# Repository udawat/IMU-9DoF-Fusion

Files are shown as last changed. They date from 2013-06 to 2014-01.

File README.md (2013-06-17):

IMU-9DoF-Fusion
===============

Explore Labs' 9 Degrees of Freedom Inertial Measurement Unit with MPU-6150 and HMC5883L and Auto Voltage Level Shifting

To work with the Code, you need the libraries installed at the right place.
Following libraries are required to be copied inside the libraries folder:

I2Cdev - by Jeff Rowberg

MPU6050 - The library for MPU-6050 and MPU-6150 are Code Compatible - by Jeff Rowberg

HMC5883L - by Jeff Rowberg

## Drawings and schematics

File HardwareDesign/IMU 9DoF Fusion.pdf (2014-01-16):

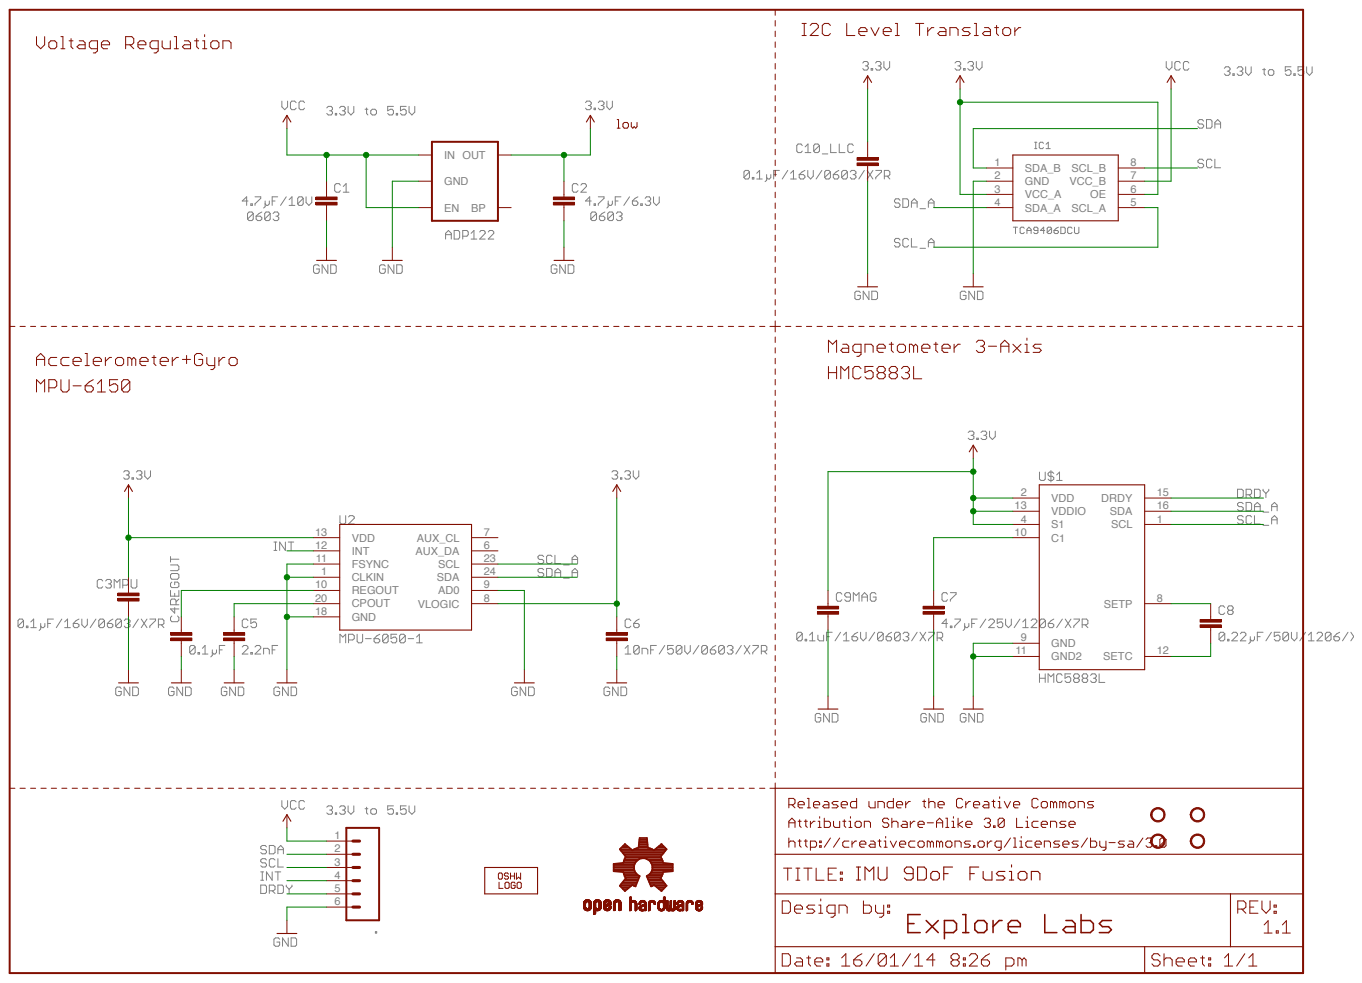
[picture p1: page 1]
VDD 13 INT 12 FSYNC 11; CLKIN; 1 REGOUT 10 CPOUT 20 GND 18; AUX_CL; AUX_DA; SCL; SDA; VLOGIC; VDD; 2 VDDIO 13; 1 SDA; SETP; SETC; DRDY; GND; 9 GND2 11; OUT; SDA_B; VCC_A; SDA_A; SCL_A; 6 VCC_B; 7 SCL_B

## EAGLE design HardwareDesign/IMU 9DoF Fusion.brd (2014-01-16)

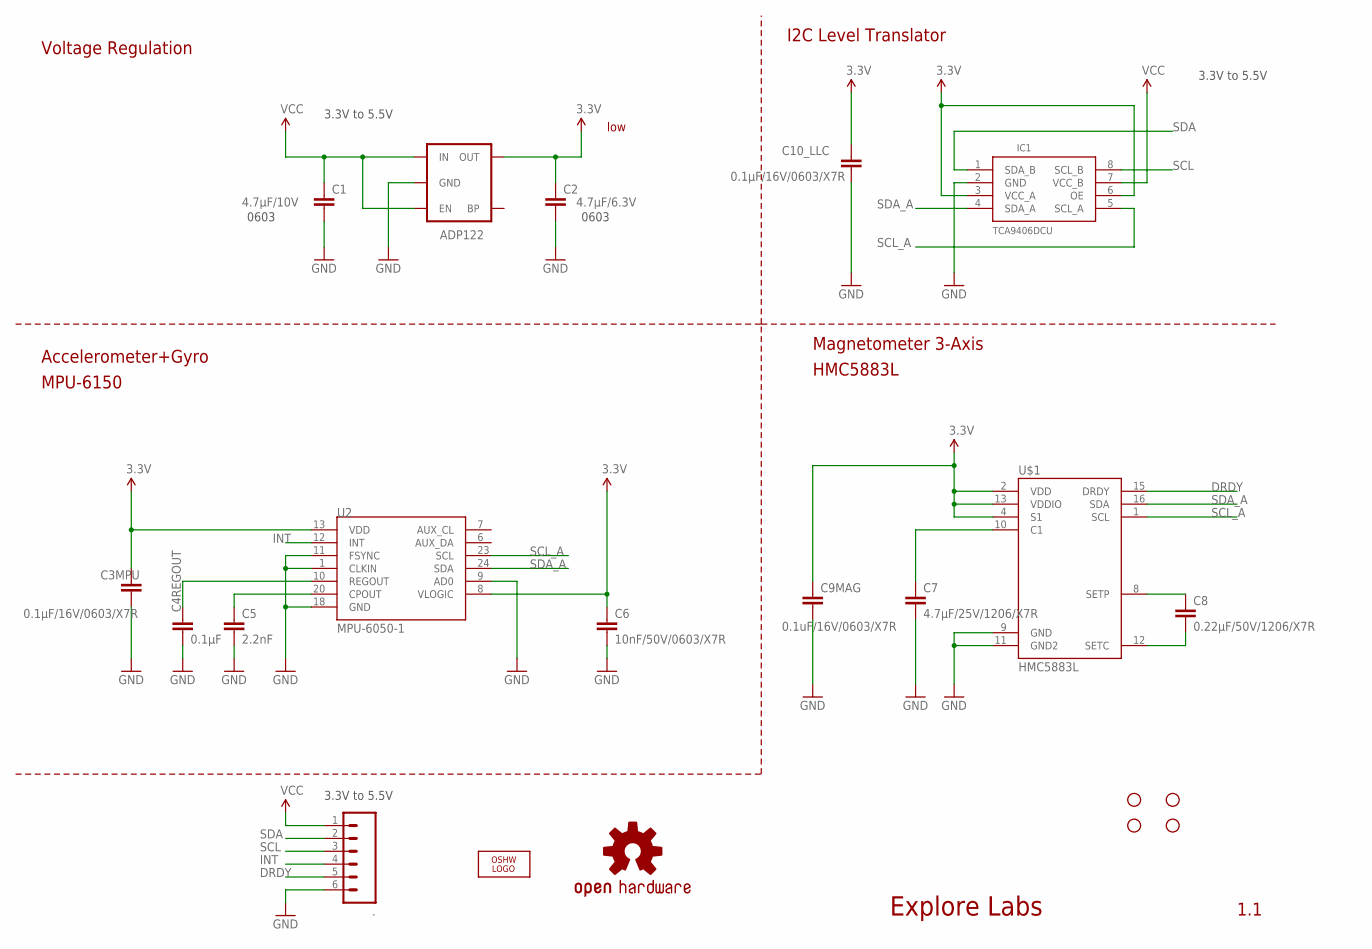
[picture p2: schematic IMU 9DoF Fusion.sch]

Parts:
.: M06SIP; 1X06
ADP122: V_REG_LDOSMD; SOT23-5
C1: 4.7µF/10V; 0603-CAP
C2: 4.7µF/6.3V; 0603-CAP
C3MPU, C10_LLC: 0.1µF/16V/0603/X7R; 0603-CAP
C4REGOUT: 0.1µF; 0603-CAP
C5: 2.2nF; 0603-CAP
C6: 10nF/50V/0603/X7R; 0603-CAP
C7: 4.7µF/25V/1206/X7R; 1206
C8: 0.22µF/50V/1206/X7R; 1206
C9MAG: 0.1uF/16V/0603/X7R; 0603-CAP
IC1: TCA9406DCU; VSSOP8
JP1, JP3, JP4, JP5: STAND-OFFTIGHT; STAND-OFF-TIGHT
LOGO1: OSHW_LOGO_FILLX0150-NT; OSHW_FILLX150_NOTEXT
U2: MPU-6050-1; QFN-24-4MM2
U$1: HMC5883L; LPCC16
U$2: OSHW-LOGOS; OSHW-LOGO-S

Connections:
3.3V: ADP122.5 (OUT), C2.1, C3MPU.1, C6.1, C9MAG.1, C10_LLC.1, IC1.3 (VCC_A), IC1.6 (OE), U2.8 (VLOGIC), U2.13 (VDD), U$1.2 (VDD), U$1.4 (S1), U$1.13 (VDDIO)
CPOUT: C5.1, U2.20 (CPOUT)
DRDY: ..5, U$1.15 (DRDY)
GND: ..6, ADP122.2 (GND), C1.2, C2.2, C3MPU.2, C4REGOUT.2, C5.2, C6.2, C7.2, C9MAG.2, C10_LLC.2, IC1.2 (GND), U2.1 (CLKIN), U2.9 (AD0), U2.11 (FSYNC), U2.18 (GND), U$1.9 (GND), U$1.11 (GND2)
INT: ..4, U2.12 (INT)
unnamed: C7.1, U$1.10 (C1)
unnamed: C8.1, U$1.8 (SETP)
unnamed: C8.2, U$1.12 (SETC)
REGOUT: C4REGOUT.1, U2.10 (REGOUT)
SCL: ..3, IC1.8 (SCL_B)
SCL_A: IC1.5 (SCL_A), U2.23 (SCL), U$1.1 (SCL)
SDA: ..2, IC1.1 (SDA_B)
SDA_A: IC1.4 (SDA_A), U2.24 (SDA), U$1.16 (SDA)
VCC: ..1, ADP122.1 (IN), ADP122.3 (EN), C1.1, IC1.7 (VCC_B)

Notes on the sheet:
Explore Labs
1.1
3.3V to 5.5V
I2C Level Translator
Voltage Regulation
MPU-6150
HMC5883L
Magnetometer 3-Axis
Accelerometer+Gyro
0603
low

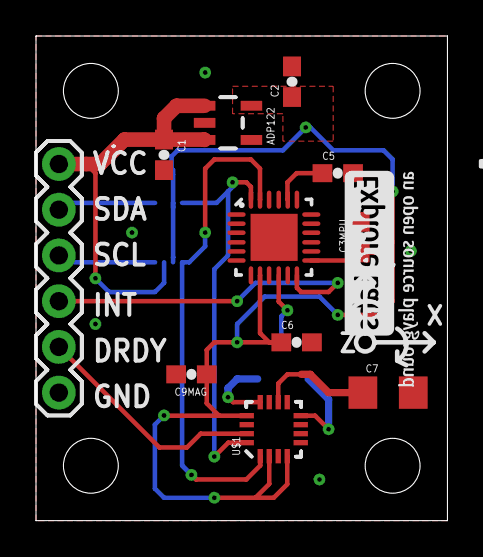
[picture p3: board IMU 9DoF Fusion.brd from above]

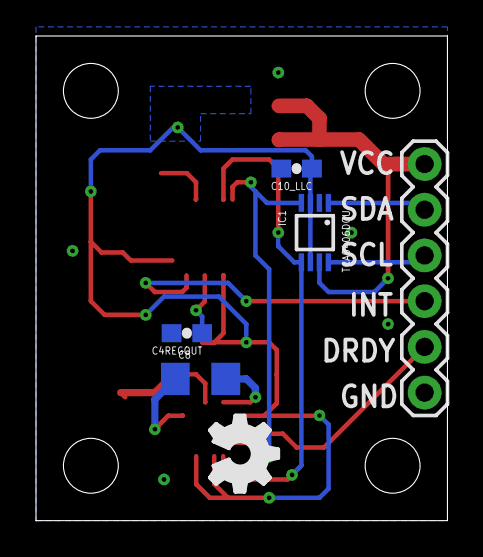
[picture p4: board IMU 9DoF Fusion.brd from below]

Board: 2 copper layers, 22.9 x 26.9 mm, 22 parts (6 on the bottom side), 14 nets.

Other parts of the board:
U$3: EXLABS_LOGO_0.25

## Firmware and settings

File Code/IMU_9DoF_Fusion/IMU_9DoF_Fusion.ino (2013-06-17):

// I2C device class (I2Cdev) demonstration Arduino sketch for MPU6050 class
// 10/7/2011 by Jeff Rowberg <jeff@rowberg.net>
// Updates should (hopefully) always be available at https://github.com/jrowberg/i2cdevlib
//
// Changelog:
//     2013-06-17 - Created IMU 9DoF sketch by combining MPU-6050/6150 and HMC5883L sketches into a single sketch
//     2013-05-04 - Added Heading Calculation in degrees
//     2011-10-07 - initial release

/* ============================================
I2Cdev device library code is placed under the MIT license
Copyright (c) 2011 Jeff Rowberg

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
THE SOFTWARE IS PROVIDED "AS IS", WITHOUT WARRANTY OF ANY KIND, EXPRESS OR
IMPLIED, INCLUDING BUT NOT LIMITED TO THE WARRANTIES OF MERCHANTABILITY,
FITNESS FOR A PARTICULAR PURPOSE AND NONINFRINGEMENT. IN NO EVENT SHALL THE
AUTHORS OR COPYRIGHT HOLDERS BE LIABLE FOR ANY CLAIM, DAMAGES OR OTHER
LIABILITY, WHETHER IN AN ACTION OF CONTRACT, TORT OR OTHERWISE, ARISING FROM,
OUT OF OR IN CONNECTION WITH THE SOFTWARE OR THE USE OR OTHER DEALINGS IN
THE SOFTWARE.
===============================================
*/

// Arduino Wire library is required if I2Cdev I2CDEV_ARDUINO_WIRE implementation
// is used in I2Cdev.h
#include "Wire.h"

// I2Cdev, MPU6050 and HMC5883L must be installed as libraries, or else the .cpp/.h files
// for both classes must be in the include path of your project
#include "I2Cdev.h"
#include "MPU6050.h"
#include "HMC5883L.h"

// class default I2C address is 0x68
// specific I2C addresses may be passed as a parameter here
// AD0 low = 0x68 (default for InvenSense evaluation board)
// AD0 high = 0x69
MPU6050 accelgyro;
HMC5883L mag;


int16_t ax, ay, az;    //  Accelerometer raw values from MPU-6150
int16_t gx, gy, gz;    //  Gyroscope raw values from MPU-6150
int16_t mx, my, mz;    //  Magnetometer raw values from HMC5883L


#define LED_PIN 13
bool blinkState = false;

void setup() {
    // join I2C bus (I2Cdev library doesn't do this automatically)
    Wire.begin();

    // initialize serial communication
    // (38400 chosen because it works as well at 8MHz as it does at 16MHz, but
    // it's really up to you depending on your project)
    Serial.begin(38400);

    // initialize device
    Serial.println("Initializing I2C devices...");
    accelgyro.initialize();
    mag.initialize();


    // verify connection
    Serial.println("Testing device connections...");
    Serial.println(accelgyro.testConnection() ? "MPU6150 connection successful" : "MPU6150 connection failed");
    Serial.println(mag.testConnection() ? "HMC5883L connection successful" : "HMC5883L connection failed");

    // configure Arduino LED for
    pinMode(LED_PIN, OUTPUT);
}

void loop() {
    // read raw accel/gyro/mag measurements from device
    accelgyro.getMotion6(&ax, &ay, &az, &gx, &gy, &gz);
    mag.getHeading(&mx, &my, &mz);

    // these methods (and a few others) are also available
    //accelgyro.getAcceleration(&ax, &ay, &az);
    //accelgyro.getRotation(&gx, &gy, &gz);

    // display tab-separated accel/gyro x/y/z values
    Serial.print("a/g/m:\t");
    Serial.print(ax); Serial.print("\t");
    Serial.print(ay); Serial.print("\t");
    Serial.print(az); Serial.print("\t");
    Serial.print(gx); Serial.print("\t");
    Serial.print(gy); Serial.print("\t");
    Serial.print(gz); Serial.print("\t");
    //Serial.print(mx); Serial.print("\t");
    //Serial.print(my); Serial.print("\t");
    //Serial.println(mz);

    // To calculate heading in degrees. 0 degree indicates North
    float heading = atan2(my, mx);
    if(heading < 0)
      heading += 2 * M_PI;
    Serial.println(heading * 180/M_PI);
    
    // blink LED to indicate activity
    blinkState = !blinkState;
    digitalWrite(LED_PIN, blinkState);
}

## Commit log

2013-05-04 initial commit
    added the gerber data with EAGLE files
    [IMU 9DoF Fusion.brd, IMU 9DoF Fusion.sch]
2013-06-17 moving folders
    changed directory structure
    [IMU 9DoF Fusion.brd, IMU 9DoF Fusion.sch]
2013-06-17 initial Code example giving raw accel/gyro values with Heading
    compiled from @Jeff Rowberg's I2C Dev Library
2013-06-17 Added required arduino libraries
    I2Cdev, MPU6050 and HMC5883L - without these libraries, the code would
    not compile.
2014-01-16 rev 1.1 schematic looks
    EAGLE version updated .epf file.
    Rev 1.1 with minor typo changes.
    [IMU 9DoF Fusion.brd, IMU 9DoF Fusion.sch]
2014-01-16 schematic in pdf format
    .pdf upload

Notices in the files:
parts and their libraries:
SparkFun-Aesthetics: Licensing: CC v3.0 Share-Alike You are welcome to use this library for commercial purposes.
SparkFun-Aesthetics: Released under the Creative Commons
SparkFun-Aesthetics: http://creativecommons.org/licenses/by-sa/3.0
